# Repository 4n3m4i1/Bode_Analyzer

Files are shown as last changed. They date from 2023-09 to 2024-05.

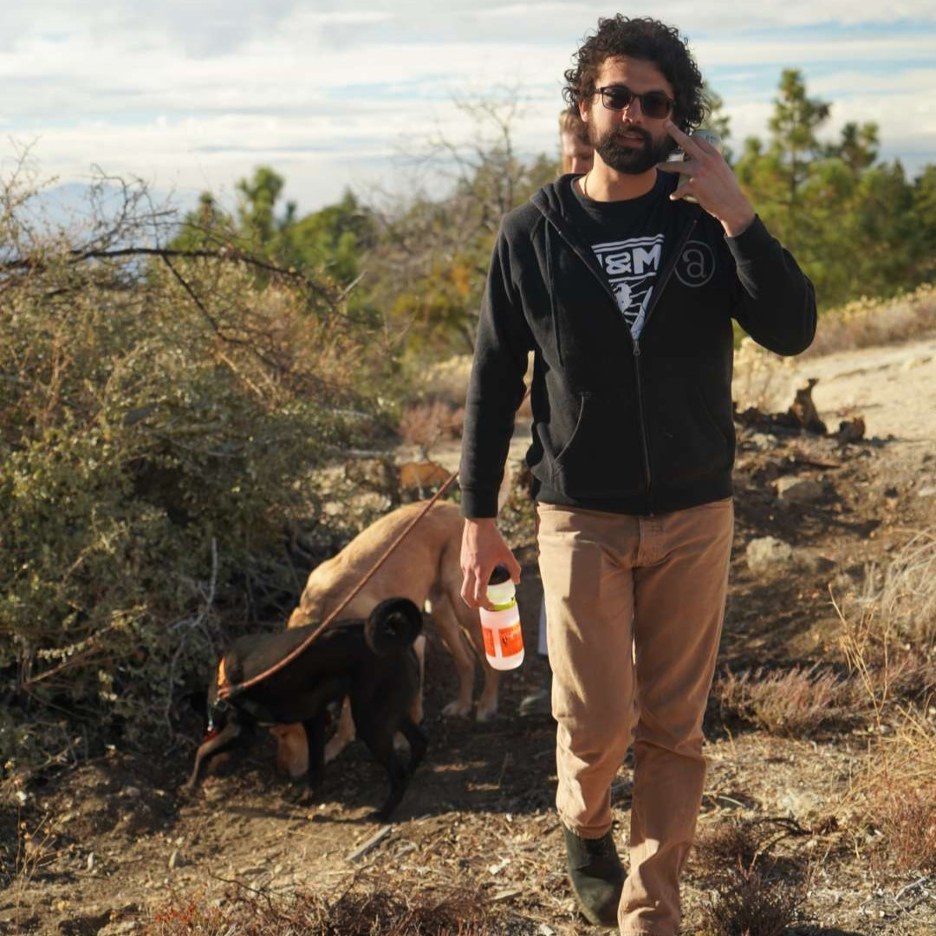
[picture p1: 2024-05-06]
App/FletApp/assets/JosephHobby.png

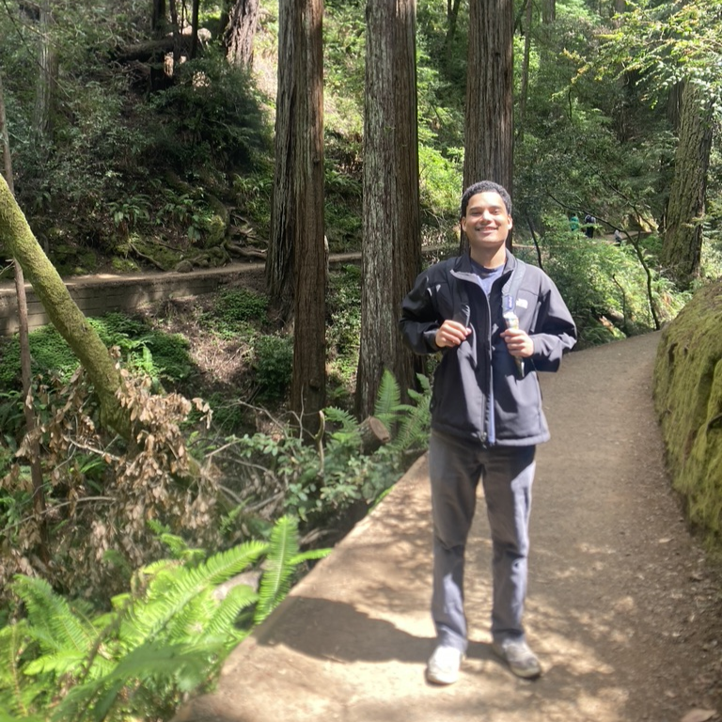
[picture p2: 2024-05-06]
App/FletApp/assets/ChristianHobby.png

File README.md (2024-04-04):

# Bode Bandits Analysis Tool
The Bode Bandits Analysis Tool provides frequency response characteristics of a multitude of filters.
A Python GUI allows interface with the tool, providing configuration and visual representations of the measured transfer function.  
  
## Hardware
Board and assembly files are provided in the repository, optimized for JLC's PCBA service.  
  
## Methods
The Least Mean Squared (LMS) adaptive filter methodology is implemented in a semi-real time fashion, allowing rapid characterization cycles to be made.  
All algorithms (LMS, FFT, Downsampling) are fully parametric, and largely user selectable on the fly. Automatic self-calibration corrects for  
component tolerance variations, VDDA magnitude, and the frontend anti-aliasing filter transfer function. DC calibration routines are run at  
startup, all transfer function calibration metrics are gathered at startup as well as upon change of any parametric setting.  
  

  
## Real Time Adjustment Parameters
- Range of frequency analysis (set ranges)
- Datapoint resolution (2^n)
- Acceptable LMS convergence error tolerances
  
## Required User Software 
- Python 3.9+
- That's it :)
  
## Repo Layout
- App: Contains the PC side of the project. Including the Python source and helper tools.
- HDL: Placeholder for potential HDL in the event a switch to a more PL based approach occurs.
- src: All C source for both the current main build as well as helper C files and feature tests.
- Documentation: All standard documentation as well as theory behind every working component, with test programs and scrips included.

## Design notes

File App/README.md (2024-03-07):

# Python GUI and Serial Input Functions

This implementation works for the data streaming test file Bode_Analyzer/src/tests/Datastreaming/Dynamic_data_output_testing

Please build this version and select the appropriate ports in the configuration 

Currently works with:
+ MacOS

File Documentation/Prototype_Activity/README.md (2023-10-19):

# Prototyping Activity
Every team member should create their own interpretation of an LMS adaptive filter.

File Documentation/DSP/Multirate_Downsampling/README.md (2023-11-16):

# Multirate Downsampling
Reduction of cost and space necessitates moving a multirate sampling solution into the digital domain.  
This example will show the process, pitfalls, and solutions with implementing such a mechanism.  
Specifically the simulation of a fixed high Fs ADC with a dynamic downsampler in the digital domain.  
In the context of this project this will allow variable rate FFT analysis and higher resolutions at lower  
frequency ranges without sacrificing analytical abilities at higher frequencies of interest.

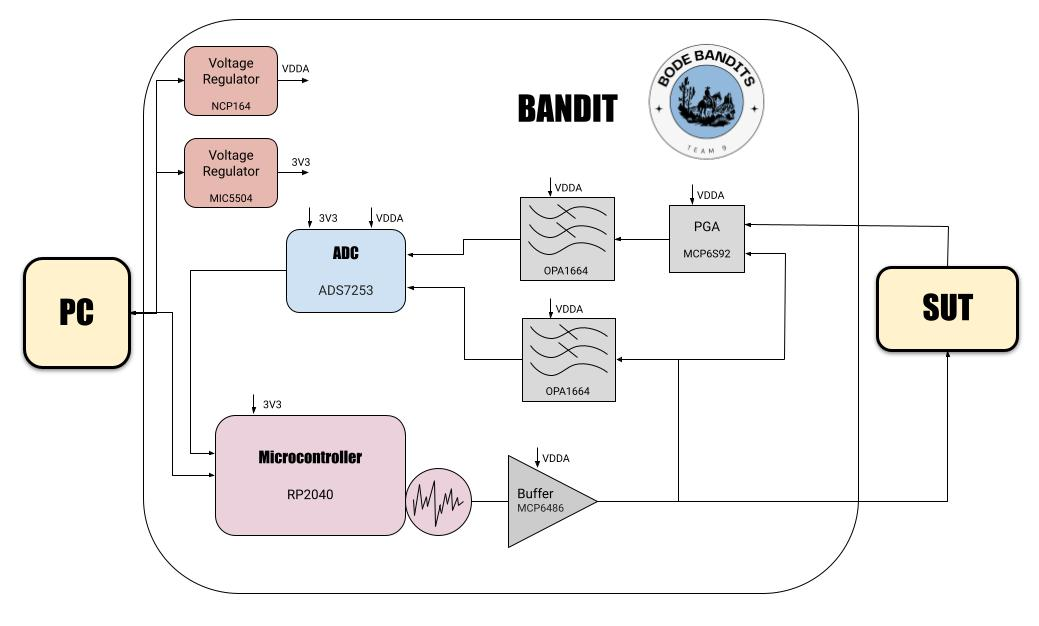
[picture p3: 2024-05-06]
App/FletApp/assets/HardwareDiagram.png

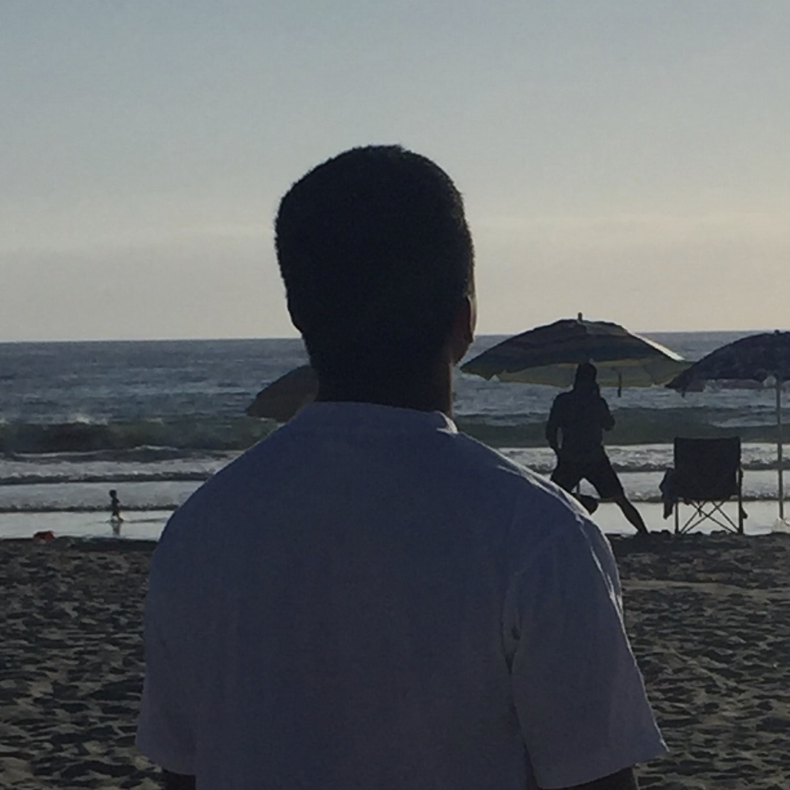
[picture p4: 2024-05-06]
App/FletApp/assets/LanceHobby.png

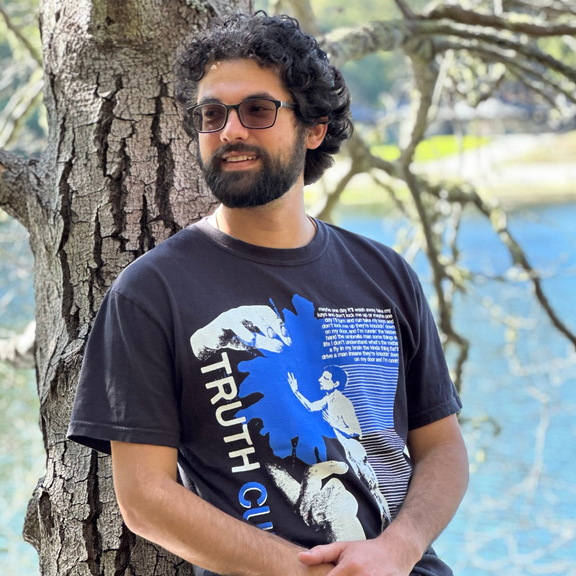
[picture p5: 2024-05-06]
App/FletApp/assets/Joseph.png

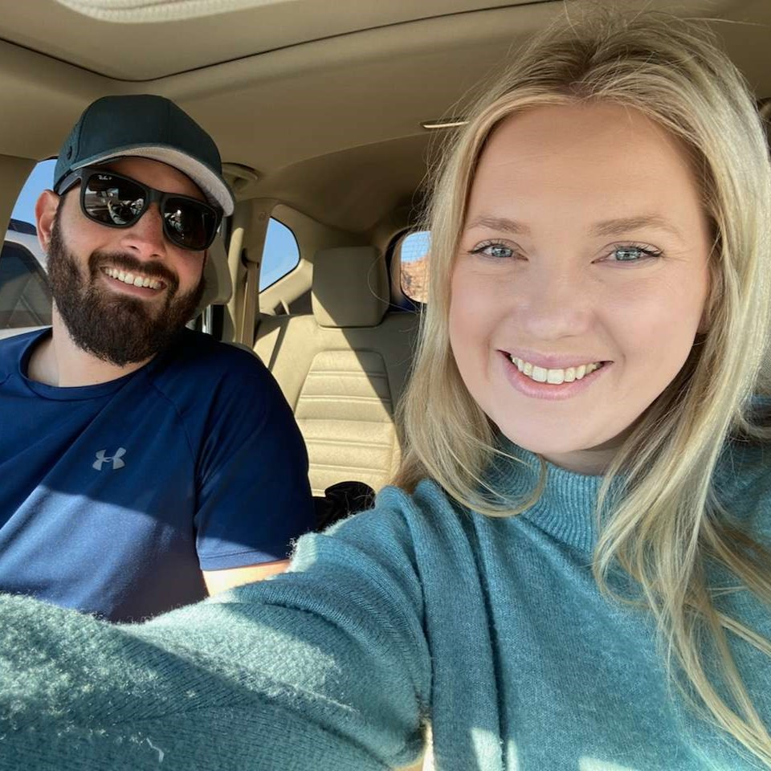
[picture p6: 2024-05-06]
App/FletApp/assets/JoshFam.png

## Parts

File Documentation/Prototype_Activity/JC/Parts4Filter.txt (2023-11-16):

200k Filter

Resistors:
2	10k
1	6k
1	5.5k
1	4k
1	2k
1	1.54k

Signal Capacitors:
5	100p 
1	75p
1	10p

Op Amps:
1	OPA1664

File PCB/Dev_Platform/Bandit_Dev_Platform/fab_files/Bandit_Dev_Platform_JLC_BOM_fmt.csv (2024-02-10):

Designator | Qty | Value | Footprint | LCSC Part Number
C1, C3, C6, C8, C12, C13, C15, C26, C28, C31, C33, C36, C48, C57, C61, C62, C64, C65, C67, C74 | 20 | 100n | Capacitor_SMD:C_0402_1005Metric | C307331
C2, C17, C18, C21, C22, C68 | 6 | 10u | Capacitor_SMD:C_0402_1005Metric | C15525
C4, C9, C14, C27, C29, C30 | 6 | 1u | Capacitor_SMD:C_0402_1005Metric | C52923
C5, C35, C49, C58 | 4 | 10n | Capacitor_SMD:C_0402_1005Metric | C15195
C7, C10, C19, C20, C41, C50 | 6 | 33p C0G | Capacitor_SMD:C_0402_1005Metric | C1562
C11, C34, C37, C63, C66 | 6 | 2u2 | Capacitor_SMD:C_0402_1005Metric | C12530
C16, C38, C46, C55 | 4 | 33p | C0G | Capacitor_SMD:C_0402_1005Metric | C1562
C23, C24 | 2 | 16n C0G | Capacitor_SMD:C_0402_1005Metric | C1549
C25, C69, C70, C71, C72, C73 | 5 | 10u 0805 | Capacitor_SMD:C_0805_2012Metric | C440198
C32 | 1 | 10n C0G | Capacitor_SMD:C_0402_1005Metric | C15195
C39, C40, C45, C47, C54, C56 | 6 | 100p | C0G | Capacitor_SMD:C_0402_1005Metric | C1546
C42, C51 | 2 | 15p C0G | Capacitor_SMD:C_0402_1005Metric | C1548
C43 | 1 | 220p | C0G | Capacitor_SMD:C_0402_1005Metric | C1530
C44, C53, C59, C60 | 4 | 47p | C0G | Capacitor_SMD:C_0402_1005Metric | C1567
C52 | 1 | 220p C0G | Capacitor_SMD:C_0402_1005Metric | C1530
D1 | 1 | LED | LED_SMD:LED_0805_2012Metric | C2297
D2 | 1 | LED_ABGR | LED_SMD:LED_Cree-PLCC4_2x2mm_CW | C2874119
FB1 | 1 | FerriteBead_Small | Inductor_SMD:L_0603_1608Metric | C1002
J5, J6 | 2 | BNC | BANDIT_PCB_Lib:DOSIN-801-0050 | C521210
P1 | 1 | USB_C_Plug_USB2.0 | Connector_USB:USB_C_Receptacle_GCT_USB4105-xx-A_16P_TopMnt_Horizontal | C963413
R1, R2, R3, R6 | 4 | 330R | Resistor_SMD:R_0402_1005Metric | C25104
R4, R5 | 2 | 27R | Resistor_SMD:R_0402_1005Metric | C25092
R7 | 1 | 100k | Resistor_SMD:R_0805_2012Metric | C149504
R8 | 1 | 150k | Resistor_SMD:R_0603_1608Metric | C22807
R9 | 1 | 50k | Resistor_SMD:R_0603_1608Metric | C23184
R10, R11 | 2 | 56k | Resistor_SMD:R_0603_1608Metric | C23206
R12, R14 | 2 | 1k | Resistor_SMD:R_0402_1005Metric | C11702
R13, R15, R25, R26 | 4 | 51k | Resistor_SMD:R_0402_1005Metric | C25794
R16, R17, R18, R19, R20, R42 | 6 | 10k | Resistor_SMD:R_0402_1005Metric | C25744
R21, R22, R23, R24 | 4 | 20R | Resistor_SMD:R_0402_1005Metric | C25092
R27 | 1 | 8.06 | Resistor_SMD:R_0402_1005Metric | C25077
R28, R32, R35, R39 | 4 | 15k | Resistor_SMD:R_0402_1005Metric | C25867
R29, R36 | 2 | 8k2 | Resistor_SMD:R_0603_1608Metric | C25981
R30, R37 | 2 | 15k | Resistor_SMD:R_0603_1608Metric | C22809
R31, R38 | 2 | 5k6 | Resistor_SMD:R_0603_1608Metric | C23189
R33, R40 | 2 | 6k2 | Resistor_SMD:R_0603_1608Metric | C4260
R34, R41 | 2 | 12k | Resistor_SMD:R_0402_1005Metric | C25752
U2 | 1 | RP2040 | Package_DFN_QFN:QFN-56-1EP_7x7mm_P0.4mm_EP3.2x3.2mm | C2040
U5 | 1 | W25Q16JVUXIQ_TR | ICDB_Curly:IC_W25Q16JVUXIQ_TR | C2843335
U11 | 1 | XC6206PxxxMR | Package_TO_SOT_SMD:SOT-23-3 | C5446
Y1 | 1 | 12.000 MHz, C9002 | Crystal:Crystal_SMD_3225-4Pin_3.2x2.5mm | C9002

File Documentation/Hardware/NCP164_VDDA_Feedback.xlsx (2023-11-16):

ADC Resolution | 12 | R Limit | 500000
Ideal Target VREF | 4.096
Part Number | Reference V | R1 | R2
NCP164ASNADJT1G | 1.1 | 50000
NCP164ASN180T1G | 1.8 | 50000
NCP164ASN280T1G | 2.8 | 50000
NCP164ASN330T1G | 3.3 | 50000

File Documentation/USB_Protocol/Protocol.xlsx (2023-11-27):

Packets
Name | Byte Number | Description
Standard Control Packet | 0x00-0x01 | Message ID
 | 0x02-0x40 | Message Specific
Message Types
Name | ID | Description | Byte Number
Ping | 0x0000 | Readback of all subsequent bytes in message to check connection | 0x02-0x40
Ping Response | 0x0001 | Readback of message data in Ping message | 0x02-0x40
RESERVED | 0x0002-0x000F
Set LMS Params | 0x0010 |  | 0x02-0x05 | Hardware Sampling Rate | uint32, Fixed 500k for BANDIT
 |  |  | 0x06-0x09 | Software Sampling Rate | uint32
 |  |  | 0x10 | Datatype | uint8
 |  |  | 0x11-0x12 | Target LMS Length | uint16
 |  |  | 0x13-0x14 | LMS Length Limit | uint16
 |  |  | 0x15-0x18 | Max Acceptable Error | Q15/Q31 Fixed point, set to 0 if unused
 |  |  | 0x19 | Start Now | uin8, if 1 start LMS process now
 |  |  | 0x20 | Loop | uint8, if 0 wait for Start Condition, if 0xFF loop forever, if 1-254 loop that many times
 |  |  | 0x21-0x40 | RESERVED

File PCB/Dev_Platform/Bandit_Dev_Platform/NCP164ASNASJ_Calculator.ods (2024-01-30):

VREF | VTGT | Scalar
1.1 | 4.096 | 2.72363636363636
PICK R1
R1 | 1.50E+05
R2 | 55073.4312416555
PICK R2
R1 | 136181.818181818
R2 | 5.00E+04

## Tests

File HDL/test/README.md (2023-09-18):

# Test and Development HDL
A collection of scratchpad Verilog that helps develop the main project.

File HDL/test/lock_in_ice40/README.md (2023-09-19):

# Lock in Test
A test of a fixed point lock in implementation for the iCE40-UP5k.  
Hardware target: Upduino3.1, iCE40-UP5k SG48

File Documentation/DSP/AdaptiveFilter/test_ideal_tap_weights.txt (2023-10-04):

0.000000000000000001
-0.000684893783392213
-0.002243092594496694
0.000000000000000001
0.017216487544020751
0.060604861756838498
0.126757470950199458
0.190091960088989709
0.216514412075680979
0.190091960088989709
0.126757470950199486
0.060604861756838546
0.017216487544020762
0.000000000000000001
-0.002243092594496697
-0.000684893783392215
0.000000000000000001

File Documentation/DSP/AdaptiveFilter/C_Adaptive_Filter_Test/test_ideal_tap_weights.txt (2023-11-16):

0.000000000000000000
-0.000011466433343440
-0.000048159680438716
-0.000070951498745996
0.000000000000000000
0.000226394896924650
0.000570593070542985
0.000843882357908127
0.000742644459879189
-0.000000000000000001
-0.001387330856962112
-0.002974017320060804
-0.003876072294410999
-0.003078546062261788
0.000000000000000002
0.004911281747189231
0.009897689392343489
0.012239432700612913
0.009302643950572093
-0.000000000000000005
-0.013947257358995015
-0.027649479941983943
-0.034045985830080311
-0.026173578588735643
0.000000000000000007
0.043288592274982135
0.096612134128292462
0.148460098539443669
0.186178664190551207
0.199977588313552862
0.186178664190551235
0.148460098539443669
0.096612134128292462
0.043288592274982128
0.000000000000000007
-0.026173578588735653
-0.034045985830080325
-0.027649479941983936
-0.013947257358995019
-0.000000000000000005
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

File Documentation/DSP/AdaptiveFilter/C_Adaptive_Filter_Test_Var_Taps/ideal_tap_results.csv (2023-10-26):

IDX | IDEAL_TAP
0 | 0.00000000000000
1 | -0.00001091022809
2 | 0.00003691750457
3 | 0.00004444100803
4 | -0.00022922248370
5 | 0.00014180415650
6 | 0.00043739642997
7 | -0.00080294793796
8 | -0.00007934189430
9 | 0.00166191275359
10 | -0.00150465174576
11 | -0.00150663631703
12 | 0.00404383713989
13 | -0.00130266073992
14 | -0.00538037299278
15 | 0.00705559340679
16 | 0.00195029364228
17 | -0.01264269610401
18 | 0.00848122079784
19 | 0.01139998150633
20 | -0.02298546385206
21 | 0.00364412373121
22 | 0.03137342546969
23 | -0.03431395331964
24 | -0.01742791236150
25 | 0.07350945086669
26 | -0.04325697180722
27 | -0.10686930523952
28 | 0.29453439078266
29 | 0.61999651565494
30 | 0.29453439078266
31 | -0.10686930523952
32 | -0.04325697180722
33 | 0.07350945086669
34 | -0.01742791236150
35 | -0.03431395331964
36 | 0.03137342546969
37 | 0.00364412373121
38 | -0.02298546385206
39 | 0.01139998150633
40 | 0.00848122079784
41 | -0.01264269610401
42 | 0.00195029364228
43 | 0.00705559340679
44 | -0.00538037299278
45 | -0.00130266073992
46 | 0.00404383713989
47 | -0.00150663631703
48 | -0.00150465174576
49 | 0.00166191275359
50 | -0.00007934189430
51 | -0.00080294793796
52 | 0.00043739642997
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

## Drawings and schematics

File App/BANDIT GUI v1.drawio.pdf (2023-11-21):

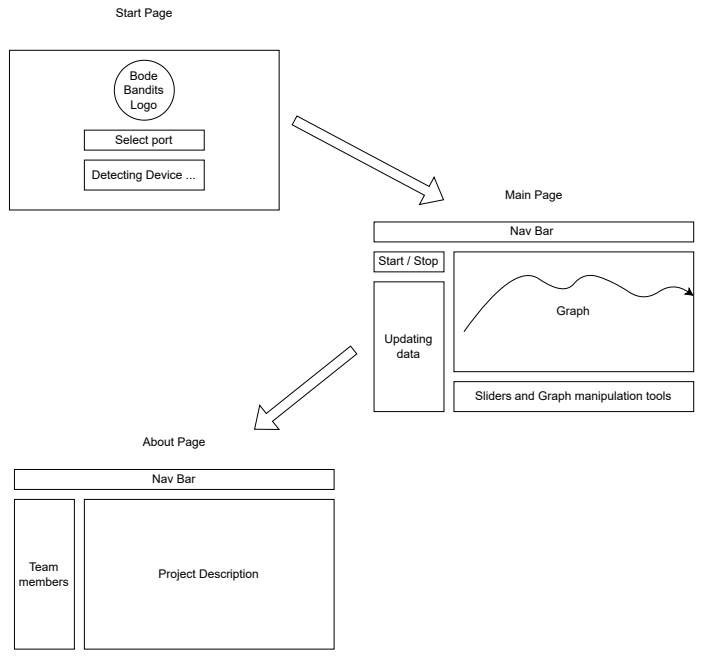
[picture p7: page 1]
Graph; Updating data; Nav Bar; Start / Stop; Main Page; Start Page; Select port; Detecting Device ...; Bode Bandits Logo; About Page; Team; members; Project Description

Sliders and Graph manipulation tools

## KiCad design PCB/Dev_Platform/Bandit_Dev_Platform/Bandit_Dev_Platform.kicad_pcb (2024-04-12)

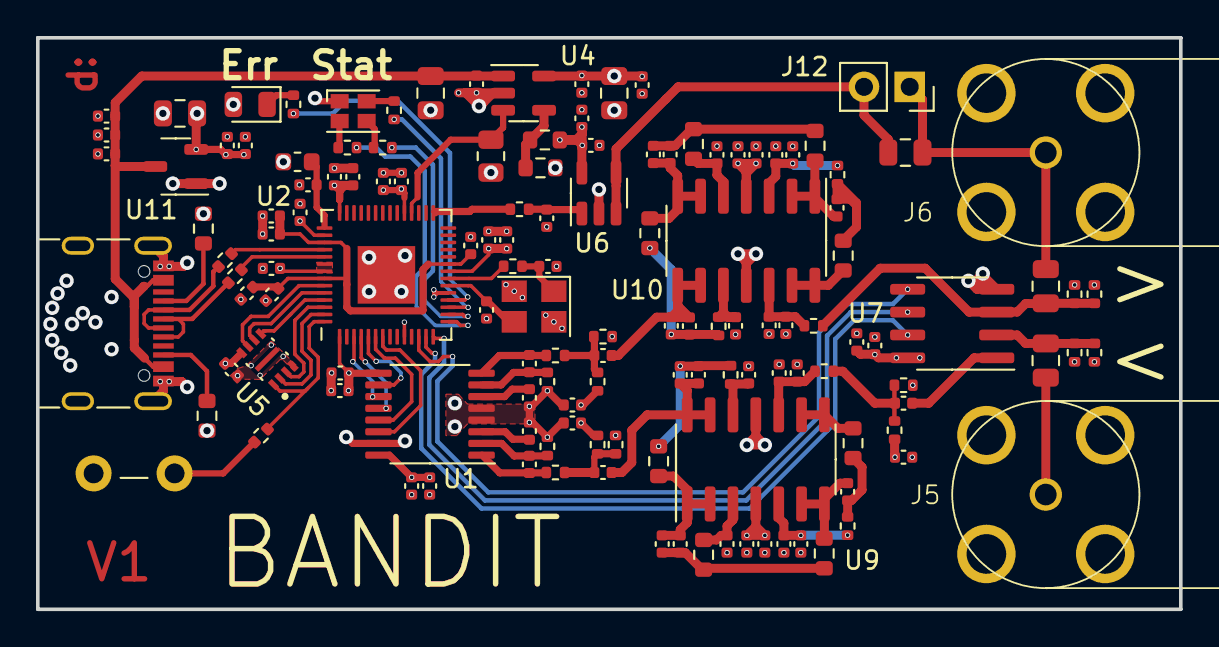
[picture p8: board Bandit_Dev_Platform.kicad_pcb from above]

Board: 4 copper layers, 63.5 x 31.8 mm, 136 parts (0 on the bottom side), 79 nets.

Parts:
C1, C3, C3#2, C6, C8, C12, C13, C15, C26, C28, C31, C33, C36, C48, C57, C61, C62, C64, C65, C67, C74: 100n; C_0402_1005Metric
C2, C17, C18, C21, C22, C68: 10u; C_0402_1005Metric
C4, C9, C14, C27, C29, C30: 1u; C_0402_1005Metric
C5, C35, C49, C58: 10n; C_0402_1005Metric
C7, C10, C16, C19, C20, C38, C41, C46, C50, C55: 33p C0G; C_0402_1005Metric
C11, C34, C37, C63, C66, C70: 2u2; C_0402_1005Metric
C23, C24: 16n C0G; C_0402_1005Metric
C25, C69, C71, C72, C73, C75: 10u 0805; C_0805_2012Metric
C32: 10n C0G; C_0402_1005Metric
C39, C40, C45, C47, C54, C56: 100p C0G; C_0402_1005Metric
C42, C51: 15p C0G; C_0402_1005Metric
C43, C52: 220p C0G; C_0402_1005Metric
C44, C53, C59, C60: 47p C0G; C_0402_1005Metric
D1: LED; LED_0805_2012Metric
D2: LED_ABGR; LED_Cree-PLCC4_2x2mm_CW
FB1: FerriteBead_Small; L_0603_1608Metric
J5, J6: BNC; DOSIN-801-0050
J12: Conn_01x02_Pin; PinSocket_1x02_P2.54mm_Vertical
P1: USB_C_Plug_USB2.0; USB_C_Receptacle_GCT_USB4105-xx-A_16P_TopMnt_Horizontal
R1, R2, R3, R6: 330R; R_0402_1005Metric
R4, R5: 27R; R_0402_1005Metric
R7: 10k; R_0805_2012Metric
R8: 150k; R_0603_1608Metric
R9: 50k; R_0603_1608Metric
R10, R11: 56k; R_0603_1608Metric
R12, R14: 1k; R_0402_1005Metric
R13, R15, R25, R26: 51k; R_0402_1005Metric
R16, R17, R18, R19, R20, R42: 10k; R_0402_1005Metric
R21, R22, R23, R24: 20R; R_0402_1005Metric
R27: 8.06; R_0402_1005Metric
R28, R32, R35, R39: 15k; R_0402_1005Metric
R29, R36: 8k2; R_0603_1608Metric
R30, R37: 15k; R_0603_1608Metric
R31, R38: 5k6; R_0603_1608Metric
R33, R40: 6k2; R_0603_1608Metric
R34, R41: 12k; R_0402_1005Metric
SW1: SW_SPST; SW_PUSH_6mm
U1: AD7253; TSSOP-16_4.4x5mm_P0.65mm
U2: RP2040; QFN-56-1EP_7x7mm_P0.4mm_EP3.2x3.2mm
U4: NCP164ASNADJT1G; SOT-23-5
U5: W25Q16JVUXIQ_TR; IC_W25Q16JVUXIQ_TR
U6: MCP6486UT-E/OT; SOT-23-5
U7: MCP6S92-E/SN; SOIC-8_3.9x4.9mm_P1.27mm
U9, U10: OPA1664; SOIC-14_3.9x8.7mm_P1.27mm
U11: XC6206PxxxMR; SOT-23-3
Y1: 12.000 MHz, C9002; Crystal_SMD_3225-4Pin_3.2x2.5mm

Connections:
+1V1: C33.1, C34.1, C62.1, C63.1, C64.1, U2.23 (DVDD), U2.45 (VREG_VOUT), U2.50 (DVDD)
+3V3: C1.1, C28.1, C29.1, C35.1, C36.1, C37.1, C61.1, C65.1, C66.1, C67.1, C68.1, C69.1, C70.1, C74.1, D1.2 (A), D2.1 (A), FB1.2, U1.9 (DVDD), U2.1 (IOVDD), U2.10 (IOVDD), U2.22 (IOVDD), U2.33 (IOVDD), U2.42 (IOVDD), U2.44 (VREG_IN), U2.48 (USB_VDD), U2.49 (IOVDD), U5.8 (VCC), U11.2 (VO)
/ADC_CSN: U1.11 (~CS), U2.3 (GPIO1)
/ADC_SCK: U1.12 (SCLK), U2.4 (GPIO2)
/ADC_SDI: U1.10 (SDI), U2.5 (GPIO3)
/ADC_SDO_A: U1.13 (SDO_A), U2.6 (GPIO4)
/ADC_SDO_B: U1.14 (SDO_B), U2.7 (GPIO5)
/CLK_12M: C10.1, U2.20 (XIN), Y1.3
/FLASH_IO0: U2.53 (QSPI_SD0), U5.5 (DI(IO0))
/FLASH_IO1: U2.55 (QSPI_SD1), U5.2 (DO(IO1))
/FLASH_IO2: U2.54 (QSPI_SD2), U5.3 (IO2)
/FLASH_IO3: U2.51 (QSPI_SD3), U5.7 (IO3)
/FLASH_SCK: U2.52 (QSPI_SCLK), U5.6 (CLK)
/LED_B: R1.2, U2.17 (GPIO14)
/LED_G: R2.2, U2.16 (GPIO13)
/LED_R: R3.2, U2.15 (GPIO12)
/PDM_WGN: R27.2, U2.29 (GPIO18)
/PGA_SCK: U2.13 (GPIO10), U7.7 (SCK)
/PGA_SI: U2.14 (GPIO11), U7.6 (SI)
/SE_SIG_A: C18.2, C39.1, C52.1, U10.8, U10.9 (-)
/SE_SIG_B: C17.2, C40.1, C43.1, U9.13 (-), U9.14
/SIG_IN: C2.1, R16.2, R17.1, R34.1
/USB_CC: P1.A5 (CC), R10.1
/USB_D+: R5.2, U2.47 (USB_DP)
/USB_D-: R4.2, U2.46 (USB_DM)
/USB_VCONN: P1.B5 (VCONN), R11.1
/USER_LED: R6.2, U2.18 (GPIO15)
/VDDA_EN: R7.2, U2.32 (GPIO21), U4.3 (EN)
/WGN_OUT: C73.2, J12.2, U6.3 (VIN-), U6.4 (VOUT)
/WGN_OUT_PORT: C72.1, C73.1, J6.1 (In), J12.1
/WGN_PGA_IN: C72.2, R13.2, R15.1, R41.1, U7.3 (CH1)
/XOUT: C7.2, R14.2, Y1.1
/~FLASH_CSN: R12.1, U2.56 (QSPI_SS), U5.1 (~CS)
/~PGA_CS: U2.12 (GPIO9), U7.5 (~CS)
GND: C1.2, C3.2, C3#2.2, C4.2, C5.2, C6.2, C7.1, C8.2, C9.2, C10.2, C11.2, C12.2, C13.2, C14.2, C15.2, C16.1, C19.1, C20.1, C21.2, C22.2, C26.2, C27.2, C28.2, C29.2, C30.2, C31.2, C32.2, C33.2, C34.2, C35.2, C36.2, C37.2, C38.1, C41.1, C42.1, C44.1, C46.1, C48.2, C49.2, C50.1, C51.1, C53.1, C55.1, C57.2, C58.2, C61.2, C62.2, C63.2, C64.2, C65.2, C66.2, C67.2, C68.2, C69.2, C70.2, C71.2, C74.2, C75.2, J5.2 (Ext), J6.2 (Ext), P1.A1 (GND), P1.A12 (GND), P1.B1 (GND), P1.B12 (GND), P1.S1 (SHIELD), R7.1, R9.1, R10.2, R11.2, R15.2, R17.2, R19.2, R21.1, R24.1, R26.2, R42.2, SW1.2 (B), U1.4 (REFGND_A), U1.5 (REFGND_B), U1.15 (GND), U2.19 (TESTEN), U2.57 (GND), U4.2 (GND), U5.4 (GND), U6.2 (VSS), U7.4 (VSS), U9.11 (V-), U10.11 (V-), U11.1 (GND), Y1.2, Y1.4
unnamed: C17.1, R18.2, R19.1, R23.1
unnamed: C18.1, R20.2, R22.1, R42.1
unnamed: C39.2, C52.2, R35.1, R36.2
unnamed: C40.2, C43.2, R28.1, R29.2
unnamed: C45.2, C60.2, R30.1, R31.2
unnamed: C47.2, R32.1, R33.2
unnamed: C54.2, C59.2, R37.1, R38.2
unnamed: C56.2, R39.1, R40.2
unnamed: D1.1 (K), R6.1
unnamed: D2.2 (BK), R1.1
unnamed: D2.3 (GK), R2.1
unnamed: D2.4 (RK), R3.1
unnamed: C25.1, J5.1 (In)
unnamed: P1.A6 (D+), R5.1
unnamed: P1.A7 (D-), R4.1
unnamed: R12.2, SW1.1 (A)
unnamed: C24.2, R24.2, U1.2 (AINM_A)
unnamed: C23.2, R21.2, U1.7 (AINM_B)
unnamed: C24.1, R23.2, U1.1 (AINP_A)
unnamed: C23.1, R22.2, U1.8 (AINP_B)
unnamed: C22.1, U1.3 (REFIO_A)
unnamed: C21.1, U1.6 (REFIO_B)
unnamed: C11.1, FB1.1, U2.43 (ADC_AVDD)
unnamed: R14.1, U2.21 (XOUT)
unnamed: R8.1, R9.2, U4.4 (PG/ADJ)
unnamed: C32.1, R27.1, U6.1 (VIN+)
unnamed: C25.2, R25.2, R26.1, U7.2 (CH0)
unnamed: C2.2, U7.1 (VOUT)
unnamed: C44.2, R30.2, U9.3 (+)
unnamed: C45.1, C60.1, R29.1, U9.1, U9.2 (-)
unnamed: C16.2, C46.2, R32.2, U9.5 (+)
unnamed: C47.1, R31.1, U9.6 (-), U9.7
unnamed: C19.2, C50.2, R34.2, U9.10 (+)
unnamed: R33.1, U9.8, U9.9 (-)
unnamed: C42.2, R28.2, U9.12 (+)
unnamed: C38.2, C55.2, R39.2, U10.3 (+)
unnamed: C56.1, R38.1, U10.1, U10.2 (-)
unnamed: C53.2, R37.2, U10.5 (+)
unnamed: C54.1, C59.1, R36.1, U10.6 (-), U10.7
unnamed: C51.2, R35.2, U10.10 (+)
unnamed: C20.2, C41.2, R41.2, U10.12 (+)
unnamed: R40.1, U10.13 (-), U10.14
VBUS: C3.1, C4.1, C5.1, C6.1, C75.1, P1.A4 (VBUS), P1.A9 (VBUS), P1.B4 (VBUS), P1.B9 (VBUS), U4.1 (VIN), U11.3 (VI)
VDDA: C3#2.1, C8.1, C9.1, C12.1, C13.1, C14.1, C15.1, C26.1, C27.1, C30.1, C31.1, C48.1, C49.1, C57.1, C58.1, C71.1, R8.2, R13.1, R16.1, R18.1, R20.1, R25.1, U1.16 (AVDD), U4.5 (VOUT), U6.5 (VDD), U7.8 (VDD), U9.4 (V+), U10.4 (V+)

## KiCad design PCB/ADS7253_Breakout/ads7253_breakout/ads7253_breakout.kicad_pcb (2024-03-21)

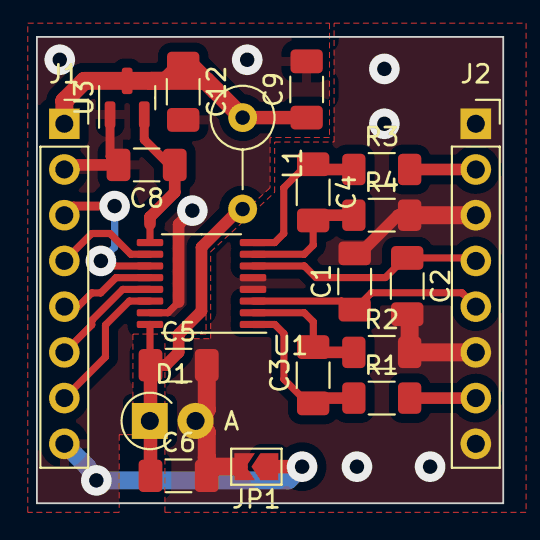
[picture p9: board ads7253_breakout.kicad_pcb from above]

Board: 2 copper layers, 25.9 x 25.9 mm, 20 parts (0 on the bottom side), 18 nets.

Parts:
C1, C2: 10u; C_1206_3216Metric_Pad1.33x1.80mm_HandSolder
C3, C4: 16p; C_1206_3216Metric_Pad1.33x1.80mm_HandSolder
C5, C9, C12: 1u; C_1206_3216Metric_Pad1.33x1.80mm_HandSolder
C6, C8: 100n; C_1206_3216Metric_Pad1.33x1.80mm_HandSolder
D1: D_Zener; D_T-1_P2.54mm_Vertical_AnodeUp
J1, J2: Conn_01x08_Pin; PinSocket_1x08_P2.54mm_Vertical
JP1: Jumper_2_Bridged; SolderJumper-2_P1.3mm_Open_TrianglePad1.0x1.5mm
L1: L; L_Axial_L7.0mm_D3.3mm_P5.08mm_Vertical_Fastron_MICC
R1, R2, R3, R4: 20R; R_1206_3216Metric_Pad1.30x1.75mm_HandSolder
U1: AD7253; TSSOP-16_4.4x5mm_P0.65mm
U3: MCP1700x-330xxTT; SOT-23

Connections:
+3V3: C8.1, U1.9 (DVDD), U3.2 (VO)
+5C: C9.1, C12.1, J1.1, L1.1, U3.3 (VI)
/AINP_A_1: J2.7, R1.2
/AINP_B_8: J2.2, R3.2
/REFDAC_A: C1.1, J2.5, U1.3 (REFIO_A)
/REFDAC_B: C2.1, J2.4, U1.6 (REFIO_B)
/SPI_CSN: J1.3, U1.11 (~CS)
/SPI_SCLK: J1.5, U1.12 (SCLK)
/SPI_SDI: J1.4, U1.10 (SDI)
/SPI_SDOA: J1.6, U1.13 (SDO_A)
/SPI_SDOB: J1.7, U1.14 (SDO_B)
GND: C8.2, C9.2, C12.2, J1.2, J1.8, JP1.1 (A), U1.15 (GND), U3.1 (GND)
GNDA: C1.2, C2.2, C5.2, C6.2, D1.2 (A), J2.1, J2.3, J2.6, J2.8, JP1.2 (B), R2.2, R4.2, U1.4 (REFGND_A), U1.5 (REFGND_B)
unnamed: C3.2, R2.1, U1.2 (AINM_A)
unnamed: C4.2, R4.1, U1.7 (AINM_B)
unnamed: C3.1, R1.1, U1.1 (AINP_A)
unnamed: C4.1, R3.1, U1.8 (AINP_B)
VDDA: C5.1, C6.1, D1.1 (K), L1.2, U1.16 (AVDD)

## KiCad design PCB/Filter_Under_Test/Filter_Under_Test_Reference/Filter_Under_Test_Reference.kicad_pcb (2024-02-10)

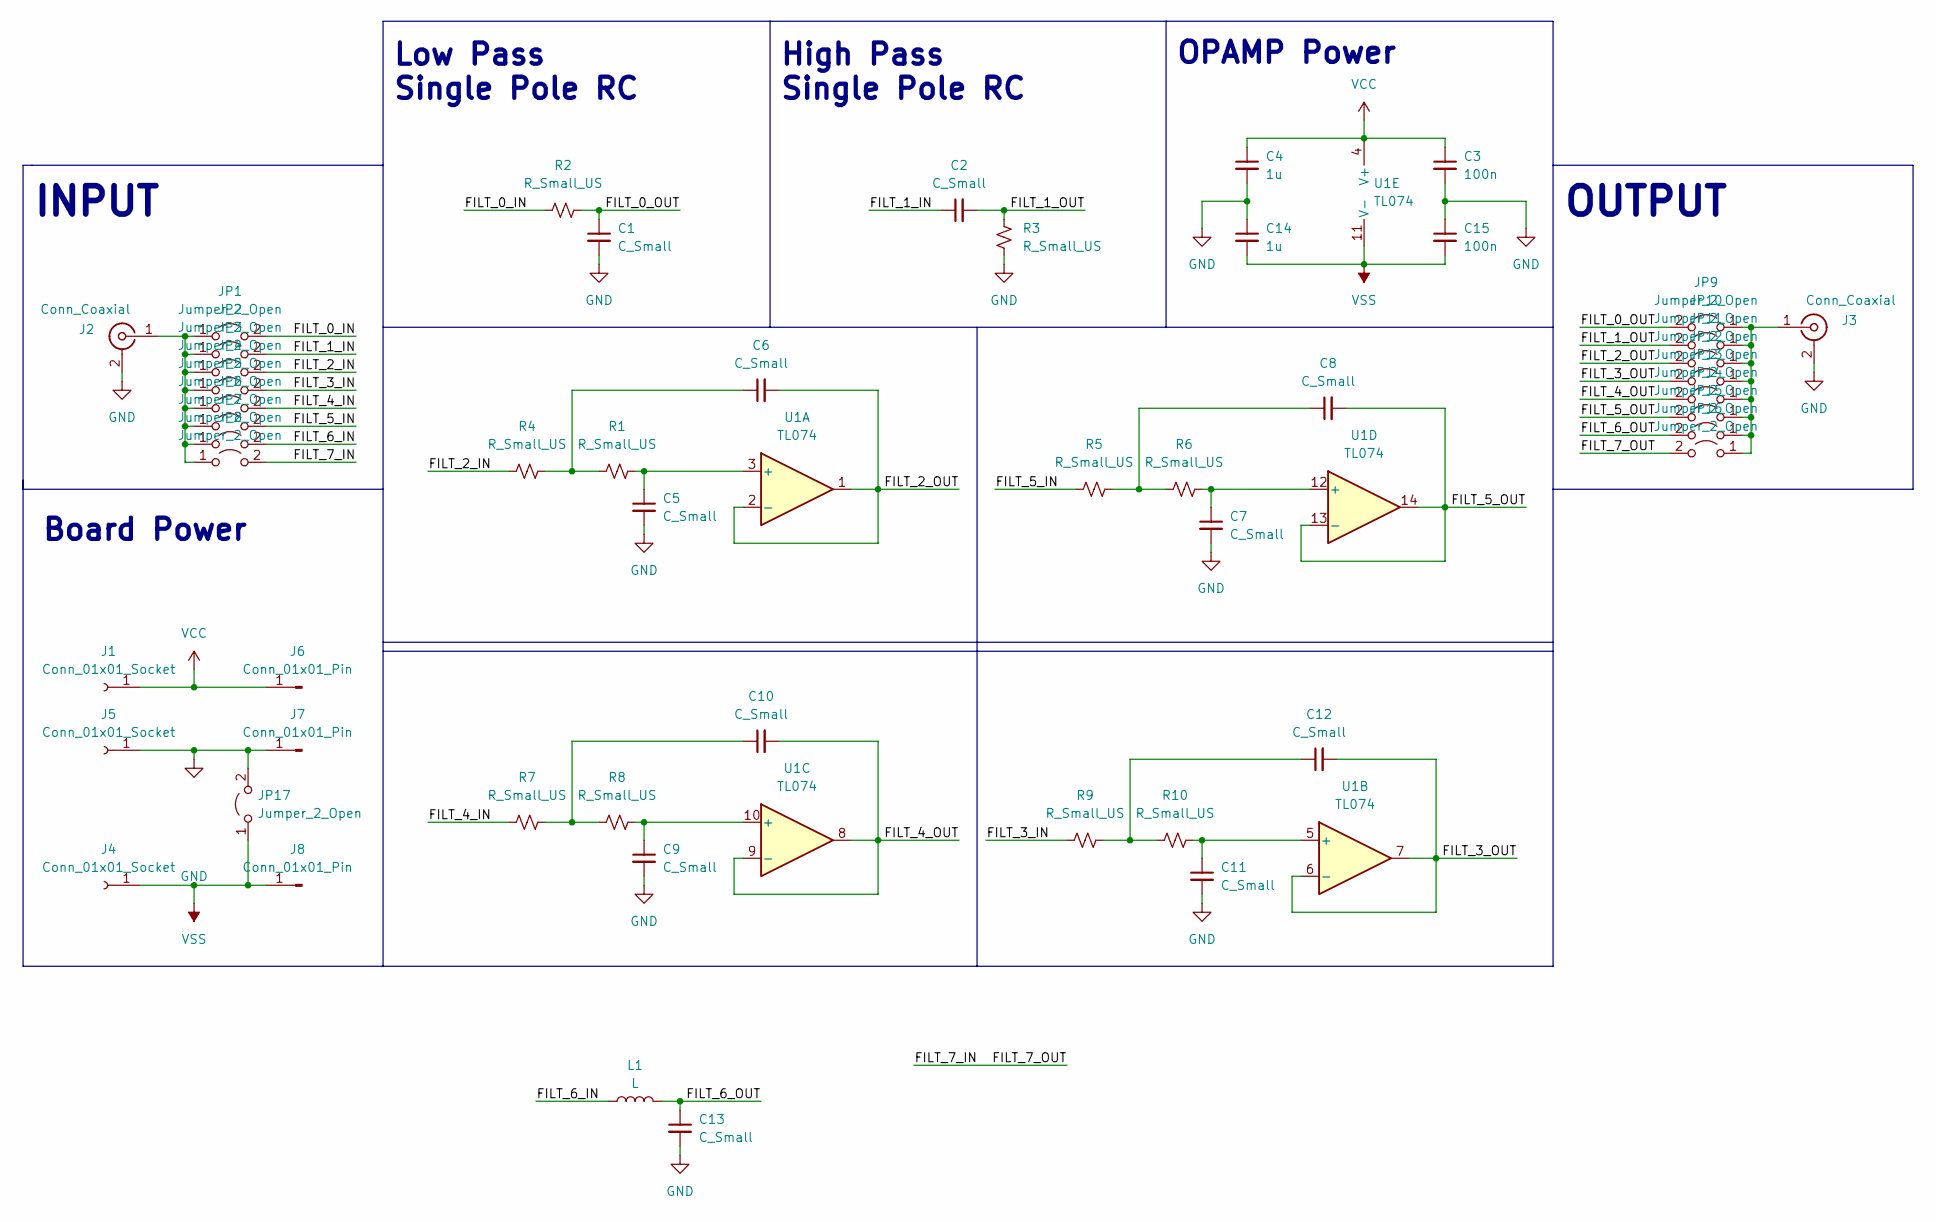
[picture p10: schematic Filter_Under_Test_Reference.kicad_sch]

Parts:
C1, C2, C5, C6, C7, C8, C9, C10, C11, C12, C13: C_Small; C_1206_3216Metric_Pad1.33x1.80mm_HandSolder
C3, C15: 100n; C_0805_2012Metric_Pad1.18x1.45mm_HandSolder
C4, C14: 1u; C_0805_2012Metric_Pad1.18x1.45mm_HandSolder
J1, J4, J5: Conn_01x01_Socket; Keystone 575 Banana
J2, J3: Conn_Coaxial; BNC_THT
J6, J7, J8: Conn_01x01_Pin; PinSocket_1x01_P2.54mm_Vertical
JP1, JP2, JP3, JP4, JP5, JP6, JP7, JP8, JP9, JP10, JP11, JP12, JP13, JP14, JP15, JP16, JP17: Jumper_2_Open; PinSocket_1x02_P2.54mm_Vertical
L1: L; L_Axial_L5.3mm_D2.2mm_P7.62mm_Horizontal_Vishay_IM-1
R1, R2, R3, R4, R5, R6, R7, R8, R9, R10: R_Small_US; R_1206_3216Metric_Pad1.30x1.75mm_HandSolder
U1: TL074; SOT23 Thin 14

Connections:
/FILT_0_IN: JP1.2 (B), R2.1
/FILT_0_OUT: C1.1, JP9.2 (B), R2.2
/FILT_1_IN: C2.1, JP2.2 (B)
/FILT_1_OUT: C2.2, JP10.2 (B), R3.1
/FILT_2_IN: JP3.2 (B), R4.1
/FILT_2_OUT: C6.2, JP11.2 (B), U1.1, U1.2 (-)
/FILT_3_IN: JP4.2 (B), R9.1
/FILT_3_OUT: C12.2, JP12.2 (B), U1.6 (-), U1.7
/FILT_4_IN: JP5.2 (B), R7.1
/FILT_4_OUT: C10.2, JP13.2 (B), U1.8, U1.9 (-)
/FILT_5_IN: JP6.2 (B), R5.1
/FILT_5_OUT: C8.2, JP14.2 (B), U1.13 (-), U1.14
/FILT_6_IN: JP7.2 (B), L1.1
/FILT_6_OUT: C13.1, JP15.2 (B), L1.2
/FILT_7_IN: JP8.2 (B), JP16.2 (B)
GND: C1.2, C3.2, C4.2, C5.2, C7.2, C9.2, C11.2, C13.2, C14.1, C15.1, J2.2 (Ext), J3.2 (Ext), J5.1, J7.1, JP17.2 (B), R3.2
unnamed: C6.1, R1.1, R4.2
unnamed: C8.1, R5.2, R6.1
unnamed: C10.1, R7.2, R8.1
unnamed: C12.1, R9.2, R10.1
unnamed: J2.1 (In), JP1.1 (A), JP2.1 (A), JP3.1 (A), JP4.1 (A), JP5.1 (A), JP6.1 (A), JP7.1 (A), JP8.1 (A)
unnamed: J3.1 (In), JP9.1 (A), JP10.1 (A), JP11.1 (A), JP12.1 (A), JP13.1 (A), JP14.1 (A), JP15.1 (A), JP16.1 (A)
unnamed: C5.1, R1.2, U1.3 (+)
unnamed: C11.1, R10.2, U1.5 (+)
unnamed: C9.1, R8.2, U1.10 (+)
unnamed: C7.1, R6.2, U1.12 (+)
VCC: C3.1, C4.1, J1.1, J6.1, U1.4 (V+)
VSS: C14.2, C15.2, J4.1, J8.1, JP17.1 (A), U1.11 (V-)

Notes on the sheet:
High Pass Single Pole RC
Low Pass Single Pole RC
OPAMP Power
OUTPUT
Board Power
INPUT

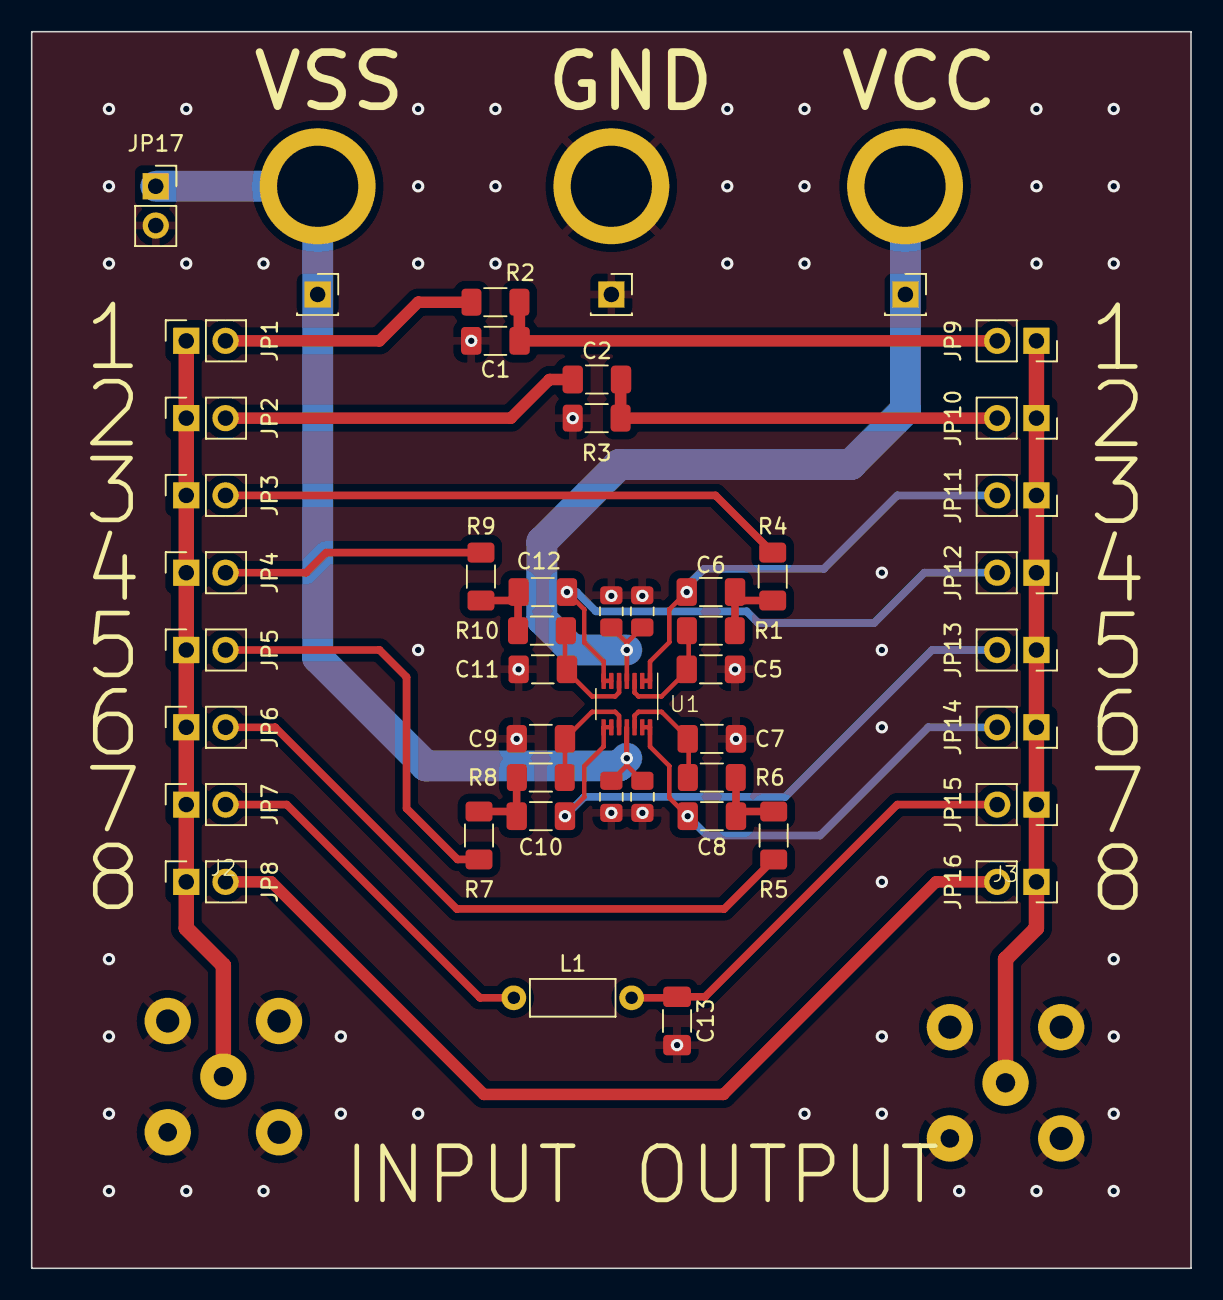
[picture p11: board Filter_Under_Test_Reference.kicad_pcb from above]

Board: 2 copper layers, 75.0 x 80.0 mm, 52 parts (0 on the bottom side), 28 nets.

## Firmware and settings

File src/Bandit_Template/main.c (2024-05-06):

/*
    Testing Defines
    DO NOT UNCOMMENT UNLESS YOU KNOW EXACTLY WHAT YOU'RE DOING!!!!!!
*/
//#define FORCE_SAMPLING_4_TESTING
#define NO_DEBUG_LED
//#define FORCESEND_TESTING
//#define FORCESEND_FAKETAPS
//#define FORCESEND_NOFFT
//#define FORCESEND_USE_REALDATA
//#define SEND_RAW_2_OUTPUT

#ifdef FORCESEND_USE_REALDATA
#include "realdata.h"
// For debug only
#include "dummy_taps.h"
#endif


#include <stdio.h>
#include "pico/stdlib.h"
#include "pico/multicore.h"
#include "hardware/i2c.h"
#include "hardware/spi.h"
#include "hardware/timer.h"
#include "hardware/pwm.h"
#include "hardware/dma.h"

#include "tusb.h"
#include "tusb_config.h"

#include "Bode_Bandit.h"


  //////////////////////////////////////////////////////////////////////
 //////////////////   GLOBAL PREALLOC BUFFERS   ///////////////////////
//////////////////////////////////////////////////////////////////////
// Preserve the abilitiy to transfer to additional buffers
//  in currently General allocated memory to interleave processing/sampling
//  more!

/*
    Current Memory Access Scheme:
    Time:       0           1           2           3
    Core 0:     Settings    N/A         N/A         FR FI
    Core 1:     XN DN       XN DN       Shared      XN DN
    Reason:     Sampling    LMS         FFT Copy    FFT / Sampling

    In theory zero contention, minor waits incurred.
    Adding a tertiary exclusive access bank would allow
    Core 0 processing during time slots 1 and 2, probably working
    on parallelized downsampling or precalculating errors for h_hat
    updates for LMS. (That's like... a good idea)
*/


  //////////////////////////////////////////////////////////////////////
 /////////////////////    GLOBAL ALLOCATIONS    ///////////////////////
//////////////////////////////////////////////////////////////////////
// Core 1 -> 0 transfer buffers
struct Transfer_Data {
    volatile bool       updated;
    volatile bool       calibration_data;
    volatile uint16_t   len;
    volatile Q15        data[TOTAL_ADAPTIVE_FIR_LEN];

    volatile uint32_t   lms_samples_processed;
    volatile Q15        lms_error;
    volatile uint16_t   lms_error_attempts;
};

struct Transfer_Data ICTXFR_A;


struct BANDIT_SETTINGS  Global_Bandit_Settings;



  //////////////////////////////////////////////////////////////////////
 /////////////////////    CORE 0 ALLOCATIONS    ///////////////////////
//////////////////////////////////////////////////////////////////////
// FFT Tap Buffers
CORE_0_MEM Q15 FR_BUFF[TOTAL_ADAPTIVE_FIR_LEN];
CORE_0_MEM Q15 FI_BUFF[TOTAL_ADAPTIVE_FIR_LEN];

// FFT Averaging buffer
CORE_0_MEM Q15 FFT_AVG_BUFF[TOTAL_ADAPTIVE_FIR_LEN];
CORE_0_MEM Q15 FFT_CAL_BUFF[TOTAL_ADAPTIVE_FIR_LEN];

// Reserve Buffer for Stored Results
CORE_0_MEM Q15 RESULTS_BUFFER[TOTAL_ADAPTIVE_FIR_LEN];


volatile CORE_0_MEM uint16_t USB_STATE;
volatile CORE_0_MEM uint16_t USB_NEXT_STATE;

volatile CORE_0_MEM bool SKIP_FFT = false;

CORE_0_MEM uint8_t  BS_RX_BF[BS_BF_LEN];
volatile CORE_0_MEM bool CORE_0_SKIP_FFT = false;
  //////////////////////////////////////////////////////////////////////
 /////////////////////    CORE 1 ALLOCATIONS    ///////////////////////
//////////////////////////////////////////////////////////////////////
struct BANDIT_LED_COLORS {
    uint8_t R;
    uint8_t G;
    uint8_t B;
    uint8_t U;
};

struct CORE_1_MEM BANDIT_LED_COLORS Bandit_RGBU;

// Sampling Banks
CORE_1_MEM Q15 X_N_0[TOTAL_BUFF_LEN];
CORE_1_MEM Q15 D_N_0[TOTAL_BUFF_LEN];

// LMS FIR For Producing Y[n]
CORE_1_MEM Q15 LMS_FIR_BANK[TOTAL_ADAPTIVE_FIR_LEN + DEFAULT_LMS_TAP_LEN];
CORE_1_MEM Q15 LMS_H_HATS[TOTAL_ADAPTIVE_FIR_LEN + DEFAULT_LMS_TAP_LEN];

CORE_1_MEM Q15 LMS_H_HATS_AVG[TOTAL_ADAPTIVE_FIR_LEN + DEFAULT_LMS_TAP_LEN];

CORE_1_MEM Q15 LMS_H_HATS_CORRECTION[TOTAL_ADAPTIVE_FIR_LEN + DEFAULT_LMS_TAP_LEN];

struct CORE_1_MEM BANDIT_CORE_1_DEBUG_REPORT Bandit_Debug_Report;

// Core 1 Defines
#define ADCRES_BITS     12u
#define ADC_RES_CODES   (1u << ADCRES_BITS)
#define ADC_VREF_CODE   0x108                   // ~2.19 V from ADS7253 DAC

#define ADC_PIO         pio1
CORE_1_MEM uint16_t     tmp_arr[ADS_READ_REG_COUNT] = {0,0,0};

struct CORE_1_MEM LMS_Fixed_Inst DFL_LMS_Inst;


  //////////////////////////////////////////////////////////////////////
 ///////////////////  CORE 0 FUNCTION DEFINITIONS   ///////////////////
//////////////////////////////////////////////////////////////////////
static void core_0_main();

static void USB_Handler(struct FFT_PARAMS *fft);

static void send_header_packet(uint16_t *h_data);
static void send_f_packets(Q15 *data, uint16_t num_samples);

static inline void fft_setup(struct FFT_PARAMS *cool_fft, uint16_t len, uint16_t maxtablesize);
static inline void fft_clear_fi(struct FFT_PARAMS *cool_fft);


  //////////////////////////////////////////////////////////////////////
 ///////////////////  CORE 1 FUNCTION DEFINITIONS   ///////////////////
//////////////////////////////////////////////////////////////////////
static void     core_1_main();
static void     transfer_results_to_safe_mem(Q15 *src, struct Transfer_Data *dst, uint16_t len);
static void     clear_adc_read_buffers();


  //////////////////////////////////////////////////////////////////////
 ////////////////////////////    Code!    /////////////////////////////
//////////////////////////////////////////////////////////////////////
// Main
// Start up in Core 0
int main(){
    board_init();
    tud_init(BOARD_TUD_RHPORT);

    init_LED_pins();

    Bandit_RGBU.R = 0;
    Bandit_RGBU.G = 0;
    Bandit_RGBU.B = 0;
    Bandit_RGBU.U = 0;
    set_RGB_levels(Bandit_RGBU.R, Bandit_RGBU.G, Bandit_RGBU.B);
    set_ULED_level(Bandit_RGBU.U);

    // Keep VDDA on, until sleep/low power modes are developed :)
    gpio_init(VDDA_EN_PAD);
    gpio_set_dir(VDDA_EN_PAD, GPIO_OUT);
    gpio_put(VDDA_EN_PAD, true);

    Setup_Semaphores();

    // Init h_hat core transfer register lengths to any known value.
    ICTXFR_A.len = 0;
    
    /*
        The AHB Lite cross bar is a 2:3 priority MUX that connects:
            - PIO0, PIO1, USB
        with the main AHB bus.

        USB falls in the lowest real time priority thus accesses to it
            (only Core 0) are regarded as lower priority.
        The access paths indicate wait-free access can be ensured for
            both white noise generation (DMA -> PIO0) and sampling
            (Core 1 <-> PIO1) if they have higher bus priority.
        
        Access allowance is done by gated high priority access, such that
            low priority access can occur. Sampling is not continuous,
            WGN generation is not continuous. But during their runtimes
            BOTH need 0 collisions.
    */

    // Allow Core 1 to have priority access to AHB Lite Bus
    //  This ensures the timing of sampling is deterministic
    hw_set_bits(&bus_ctrl_hw->priority, BUSCTRL_BUS_PRIORITY_PROC1_BITS);

    // Tenative allowance for High Priority DMA R/W access to AHB and APB
    //  buses for uninterrupted white noise generation.
    hw_set_bits(&bus_ctrl_hw->priority, BUSCTRL_BUS_PRIORITY_DMA_W_BITS);
    hw_set_bits(&bus_ctrl_hw->priority, BUSCTRL_BUS_PRIORITY_DMA_R_BITS);

    // Wait for bus priority changes to be applied.
    //  "In normal circumstances this occurs almost immediately"
    while(!bus_ctrl_hw->priority_ack);

    // Setup to count AHB-Lite MUX collisions
    bus_ctrl_hw->counter[0].value = 0;
    bus_ctrl_hw->counter[0].sel = arbiter_fastperi_perf_event_access_contested;


    // Initialize Status LEDs,
    //  Sequence Seen on Proper Init
    set_RGB_levels(BANDIT_PINK_SUPER_ARGUMENT);
    set_ULED_level(Bandit_RGBU.U = 10);

    // Setup for peripherals done on core 0
    multicore_launch_core1(core_1_main);
    core_0_main();
    // We should NEVER be here!!!
    while(1){
        // need something here to indicate we messed up.
        tight_loop_contents();
    }

}

  //////////////////////////////////////////////////////////////////////
 /////////////////    Core 0 Main Loop    /////////////////////////////
//////////////////////////////////////////////////////////////////////
static void core_0_main(){
    // Claim lock on settings until Core 0 can deal with initialization
    //  prevents Core 1 from starting any processing without settings
    //  in place.
    
    Acquire_Lock_Blocking(INTERCORE_SETTINGS_LOCK);
    
    // Do not start updated to prevent useless DSP cycling
    Global_Bandit_Settings.updated = false;
    Global_Bandit_Settings.settings_bf = BANDIT_DFL_SETTINGS;
    Global_Bandit_Settings.manual_tap_len_setting = 0;
    Global_Bandit_Settings.manual_error_limit = 0;
    Global_Bandit_Settings.manual_freq_range = 0;
    Global_Bandit_Settings.manual_lms_offset = 0;
    Global_Bandit_Settings.skip_lms = false;
    CLR_BANDIT_SETTING(Global_Bandit_Settings.settings_bf, BS_AUTO_RUN);
    SET_BANDIT_SETTING(Global_Bandit_Settings.settings_bf, BS_AUTO_SEND);

    Release_Lock(INTERCORE_SETTINGS_LOCK);

    // Setup Structs and Default Parameters for FFT
    struct FFT_PARAMS cool_fft;
    fft_setup(&cool_fft, DEFAULT_LMS_TAP_LEN, (uint16_t)SINTABLESIZE);

    // Initialize tinyUSB with board and start listening for start char from GUI
    tud_cdc_n_set_wanted_char(CDC_CTRL_CHAN, START_CHAR);
    USB_NEXT_STATE = USB_INIT;
    tud_cdc_n_set_wanted_char(CDC_CTRL_CHAN, START_CHAR);
    // USB State Machine, Settings Application, FFT

    uint32_t pace_timer = timer_hw->timerawl;
    //uint32_t pace_time_limit = 31250;
    uint32_t pace_time_limit = 100000;

    bool is_calibration_data = false;
    Q15 calibration_max = 0;

    while(1){
        tud_cdc_n_set_wanted_char(CDC_CTRL_CHAN, START_CHAR);
        tud_task();
        USB_STATE = USB_NEXT_STATE;

        //volatile uint32_t spinlock_irq_status_A;

        switch(USB_STATE) {
            case USB_INIT: {
                //need idle work until GUI is ready
                tud_task();
                USB_NEXT_STATE = USB_FFT_DATA_COLLECT;
            }
            break;
            
            case USB_APPLY_SETTINGS: {
                USB_NEXT_STATE = USB_FFT_DATA_COLLECT;
            }
            break;

            case USB_FFT_DATA_COLLECT: {
                // Acquire safe access to FFT mem, can use 2 locks for ping pong access
                tud_task();

                struct Transfer_Data *data_src;

                Acquire_Lock_Blocking(INTERCORE_FFTMEM_LOCK_A);
                pace_timer = timer_hw->timerawl;
                data_src = &ICTXFR_A;
                tud_task();
                
                if(!data_src->updated){
                    // FFT Data wasn't updated, shouldn't happen given semaphore
                    //  pacing structure
                    Release_Lock(INTERCORE_FFTMEM_LOCK_A);
                    USB_NEXT_STATE = USB_FFT_DATA_COLLECT;
                } else {
                    // If there is new FFT data to be had
                    data_src->updated = false;
                    // If data is all zeros (Core 1 probably gave up on convergence)
                    //  or the length is zero (P R O B L E M)
                    //  then don't run the FFT
                    bool allzeros = true;

                    is_calibration_data = data_src->calibration_data;

                    if(data_src->len && !SKIP_FFT){
                        // Apply windowing here if needed!!!
                        
                        fft_setup(&cool_fft, data_src->len, (uint16_t)SINTABLESIZE);

                        for(uint16_t n = 0; n < data_src->len; ++n){
                            if((cool_fft.fr[n] = data_src->data[n])) allzeros = false;
                            cool_fft.fi[n] = 0;
                        }
                    }

#ifdef FORCESEND_TESTING 
                    USB_NEXT_STATE = USB_RUN_DMC_JK_RUN_FFT;
#else
                    if(allzeros && !SKIP_FFT){
                        Release_Lock(INTERCORE_FFTMEM_LOCK_A);
                        USB_NEXT_STATE = USB_FFT_DATA_COLLECT;
                    } else {
                        USB_NEXT_STATE = USB_RUN_DMC_JK_RUN_FFT;
                    } 
#endif     
                }
            }
            break;
            
            case USB_RUN_DMC_JK_RUN_FFT: {
                tud_task();
                if(!SKIP_FFT){
                    FFT_fixdpt(&cool_fft);      // Run FFT
                    FFT_mag(&cool_fft);         // Extract magnitude, output in fft.fr
                    cool_fft.num_samples >>= 1; // Print only half of fft result, dodge reflected stuff
                    
                    if(is_calibration_data){
                        Q15 maxval = 0;
                        for(uint_fast16_t n = 0; n < cool_fft.num_samples; ++n){
                            if(cool_fft.fr[n] > maxval) maxval = cool_fft.fr[n];
                            //FFT_CAL_BUFF[n] = cool_fft.fr[n];
                            FFT_AVG_BUFF[n] = 0;
                        }

                        for(uint_fast16_t n = 0; n < cool_fft.num_samples; ++n){
                            FFT_CAL_BUFF[n] = maxval - cool_fft.fr[n];
                        }
                        
                        calibration_max = maxval;
                        
                    } else {
                        Q15 maxval = 0;
                        for(uint_fast16_t n = 0; n < cool_fft.num_samples; ++n) if(cool_fft.fr[n] > maxval) maxval = cool_fft.fr[n];

                        Q15 normalize_calibration = div_Q15(calibration_max, maxval);

                        for(uint_fast16_t n = 0; n < cool_fft.num_samples; ++n){
                            FFT_AVG_BUFF[n] += cool_fft.fr[n];
                            FFT_AVG_BUFF[n] >>= 1;
                            cool_fft.fr[n] = FFT_AVG_BUFF[n];
                           // cool_fft.fr[n] -= mul_Q15(FFT_CAL_BUFF[n], normalize_calibration);
                            //cool_fft.fr[n] <<= 3;    
                        }
                    }
                } else {
                    for(uint16_t n = 0; n < ICTXFR_A.len; ++n){
                        cool_fft.fr[n] = ICTXFR_A.data[n];
                        // Debug
                        //cool_fft.fr[n] = (Q15)n;
                    }    
                    cool_fft.num_samples = ICTXFR_A.len;
                }
                

#ifdef FORCESEND_NOFFT
                for(uint16_t n = 0; n < ICTXFR_A.len; ++n){
                        cool_fft.fr[n] = ICTXFR_A.data[n];
                }
#else
                
                
                // Raw Core 1 data bypass
                //if(CORE_0_SKIP_FFT){
                //    for(uint16_t n = 0; n < ICTXFR_A.len; ++n){
                //        cool_fft.fr[n] = ICTXFR_A.data[n];
                //    }
                //}
#endif

                // Free memory constraints
                //  stall for limiting packets per second
                if(!SKIP_FFT) while(timer_hw->timerawl - pace_timer < pace_time_limit) tud_task();
                // LMS Sends 2x as many bytes as usual FFT packets, so slow down A LOT
                else while(timer_hw->timerawl - pace_timer < (pace_time_limit << 1)) tud_task();
                Release_Lock(INTERCORE_FFTMEM_LOCK_A);
                tud_task();

                if(is_calibration_data) USB_NEXT_STATE = USB_FFT_DATA_COLLECT;
                else USB_NEXT_STATE = USB_SEND_TUSB;
            }
            break;

            case USB_SEND_TUSB: {
                // Transmit FFT Data to computer
                tud_task();
#ifdef FORCESEND_TESTING  
#ifndef FORCESEND_NOFFT
                // knock down giant DC peak...
                //for(uint16_t n = 0; n < cool_fft.log2_num_samples - 3; ++n){
                //    cool_fft.fr[n] = cool_fft.fr[cool_fft.log2_num_samples - 1];
                //}
                cool_fft.fr[0] = cool_fft.fr[1];
#endif                
                send_f_packets(cool_fft.fr, cool_fft.num_samples);
                tud_task();
                busy_wait_ms(100);
#else
                //if(!SKIP_FFT) cool_fft.fr[0] = cool_fft.fr[1];
                USB_Handler(&cool_fft);     //send data to GUI through tusb
#endif
                USB_NEXT_STATE = USB_FFT_DATA_COLLECT;
            }
            break;

            case USB_SEND_CORE_DEBUG: {
                // indicate to CORE 1 debug report is wanted
                Acquire_Lock_Blocking(INTERCORE_CORE_1_DBG_LOCK);

                // idk yet

                Release_Lock(INTERCORE_CORE_1_DBG_LOCK);
                USB_NEXT_STATE = USB_FFT_DATA_COLLECT;
            }
            break;
            
            default: {
                USB_NEXT_STATE = USB_FFT_DATA_COLLECT;
            }
            break; //need debug for USB_STATE error

        }

        
    }
}

  //////////////////////////////////////////////////////////////////////
 /////////////////    Core 1 Main Loop    /////////////////////////////
//////////////////////////////////////////////////////////////////////
static void core_1_main(){
    busy_wait_us_32(1000);
    Acquire_Lock_Blocking(INTERCORE_CORE_1_DBG_LOCK);
    Bandit_Debug_Report.epoch_core_1_boot_us = timer_hw->timelr;
    uint8_t Bandit_Calibration_State = BANDIT_UNCALIBRATED;
    Q15 Bandit_DC_Offset_Cal = 0;
    
    
    DFL_LMS_Inst.tap_len = DEFAULT_LMS_TAP_LEN;
    DFL_LMS_Inst.max_convergence_attempts = 4;

    // Setup LMS controller and buffering
    struct LMS_Fixed_Inst LMS_Inst;
    
    LMS_Struct_Init(&DFL_LMS_Inst, 
                        0x0666, 
                        0x2000, 
                        0, 
                        STD_MAX_SAMPLES, 
                        0
                        ); // Errors are just straight guesses rn, offset as well
    DFL_LMS_Inst.tap_len = DEFAULT_LMS_TAP_LEN;
    DFL_LMS_Inst.d_n = D_N_0;
    DFL_LMS_Inst.x_n = X_N_0;
    DFL_LMS_Inst.iteration_ct = STD_MAX_SAMPLES;
    DFL_LMS_Inst.d_n_offset = 0;
    DFL_LMS_Inst.learning_rate = 0x0020;    // 0.001
    DFL_LMS_Inst.averaging_counts_limit = 2;
    //DFL_LMS_Inst.learning_rate = 0x0003;    // 0.0001
    //DFL_LMS_Inst.learning_rate = 0x0008;    // 0.00025

    // Set default settings to local struct copy
    LMS_Struct_Equate(&DFL_LMS_Inst, &LMS_Inst);

    // Setup FIR component of the LMS
    struct Q15_FIR_PARAMS LMS_FIR;
    setup_Q15_FIR(&LMS_FIR, DEFAULT_LMS_TAP_LEN);
    LMS_FIR.size_true = TOTAL_ADAPTIVE_FIR_LEN;
    LMS_FIR.data = LMS_FIR_BANK;
    LMS_FIR.taps = LMS_H_HATS;
    
    LMS_Inst.max_convergence_attempts = 4;
    LMS_Inst.averaging_counts_limit = 2;
    LMS_Inst.averaging_counts = 0;

    /*
        For Tap Length Update:
            - Set LMS_Inst.tap_len = len
            - setup_Q15_FIR(&LMS_FIR, len)
            - len must be power of 2
    */

    Q15 DOWNSAMPLE_SAMP_BUFFR[DOWNSAMPLE_LEN];

    struct Q15_FIR_PARAMS CUT_125KHZ;
    setup_Q15_FIR(&CUT_125KHZ, DOWNSAMPLE_LEN);
    CUT_125KHZ.size_true = DOWNSAMPLE_LEN;
    CUT_125KHZ.taps = h125_taps;
    CUT_125KHZ.data = DOWNSAMPLE_SAMP_BUFFR;
   
    struct Q15_FIR_PARAMS CUT_62KHZ;
    setup_Q15_FIR(&CUT_62KHZ, DOWNSAMPLE_LEN);
    CUT_62KHZ.size_true = DOWNSAMPLE_LEN;
    CUT_62KHZ.taps = h62_taps;
    CUT_62KHZ.data = DOWNSAMPLE_SAMP_BUFFR;

    struct Q15_FIR_PARAMS CUT_31KHZ;
    setup_Q15_FIR(&CUT_31KHZ, DOWNSAMPLE_LEN);
    CUT_31KHZ.size_true = DOWNSAMPLE_LEN;
    CUT_31KHZ.taps = h31_taps;
    CUT_31KHZ.data = DOWNSAMPLE_SAMP_BUFFR;


    /*
        Initiate frontend PGA/MUX
            Set channel 0 (D_N), 1x gain
    */
    spi_inst_t *mcp_spi = spi1;
    MCP6S92_Init(mcp_spi, PGA_CSN_PAD, PGA_SCK_PAD, PGA_SI_PAD);
    // Don't init frontend PGA until calibration
    //MCP6S92_Send_Command_Raw(mcp_spi, MCP6S92_INSTR(MCP6S92_REG_WRITE, MCP6S92_CHANNEL_REGISTER), MCP6S92_CHAN_0, PGA_CSN_PAD);
    //MCP6S92_Send_Command_Raw(mcp_spi, MCP6S92_INSTR(MCP6S92_REG_WRITE, MCP6S92_GAIN_REGISTER), MCP6S92_x1_GAIN, PGA_CSN_PAD);
    

    /*
        Initialize ADC SPI w/ pio1
    */
    pio_ads7253_spi_init(pio1, 16, 1, 0, ADC_CSN_PAD, ADC_SDI_PAD, ADC_SDO_A_PAD, 0);

    Bandit_RGBU.B = 0;
    Bandit_RGBU.R = 0;
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

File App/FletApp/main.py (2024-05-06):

import matplotlib.axes
import matplotlib.axis
import matplotlib.figure
import matplotlib.lines
import webbrowser
from generic_include import *
from generic_include import BANDIT_SETTINGS_BYTES
from assets.ref import *
import serial
import webbrowser
# from enum import IntEnum
# import serial.tools.list_ports_osx as list_ports_osx
# import serial.tools.list_ports_windows as list_ports_windows
# import serial.tools.list_ports_linux as list_ports_linux
import serial.tools.list_ports as list_ports
import platform
import matplotlib
matplotlib.use('agg')
import matplotlib.pyplot as plt
import matplotlib.ticker as ticker
from itertools import chain
import struct 
import flet as ft
from flet.matplotlib_chart import MatplotlibChart
from flet import RouteChangeEvent
from multiprocess import Queue, Event
import multiprocessing
from multiprocessing import Queue, Lock
from threading import Thread
import time
from bitstring import BitArray
import numpy as np
os = platform.system()
negative_allowed_event = Event()
negative_allowed_event.clear()
start_event = Event()
queue_max = Event()
queue_max.clear()
settings_event = Event()

port_selections = []
# if os == MACOS_STR: 
#     for port in list_ports_osx.comports():
#         port_selections.append(ft.dropdown.Option(str(port).split(".")[1]))
# elif os == LINUX_STR:
#     for port in list_ports_linux.comports():
#         port_selections.append(ft.dropdown.Option(str(port)))
# # elif os == WINDOWS_STR:
# #     for port in list_ports_windows.comports():
# #         port_selections.append(ft.dropdown.Option(str(port)))
# else: pass

for port in list_ports.comports():
    print(port)
    port_selections.append(ft.dropdown.Option(str(port)))

taps_list =[]
size = len(parametric_taps)
for index in range(size):
    taps_list.append(ft.dropdown.Option(key=parametric_taps[index]))


range_list = []
size1 = len(frequency_ranges)
for index1 in range(size1):
    range_list.append(ft.dropdown.Option(key=index1, text=frequency_ranges[index1]))

data_port = Port()
ctrl_port = Port()

# init_graph = [0 for i in range(NUM_VALUES)]

Settings_Queue = Queue()
GraphEvent = Event()
##########################################################################################SERIALREAD
def serial_read(dataPort: Port, ctrlPort: Port, data_Queue: Queue, settings_Queue: Queue, page, lock):
    BYTES_PER_NUMBER = 2
    CDC_PACKET_LENGTH = 64

    def close_banner(e):
        page.banner.open = False
        page.update()
    
    x = 0
    while x < 1:
        is_conn = start_event.wait()
        try:
            if dataPort.name == ctrlPort.name:
                raise serial.SerialException
            DATACHANNEL = serial.Serial(
                port = dataPort.name,
                baudrate = 9600,
                bytesize = serial.EIGHTBITS,
                timeout = 1,

            )
            CTRLCHANNEL = serial.Serial(
                port= ctrlPort.name,
                baudrate=9600,
                bytesize = serial.EIGHTBITS,
                timeout = 1,
            )
            x = x + 1
            #send initial settings
            CTRLCHANNEL.write(b'~')
            print('start')
            CTRLCHANNEL.write(bytes(INIT_SETTINGS))
            # # # print(bytes(INIT_SETTINGS))
            # # #print(CTRLCHANNEL.read(64))
            setting = BitArray(hex=CTRLCHANNEL.read(SETTINGS_BF_LEN).hex())
            bandit_sett_bf = BitArray(hex=CTRLCHANNEL.read(4).hex())
            newfreqrange = BitArray(hex=CTRLCHANNEL.read(1).hex())
            newtaplen = BitArray(hex=CTRLCHANNEL.read(2).hex())
            new_err_limit = BitArray(hex=CTRLCHANNEL.read(2).hex())
            new_lms_offset = BitArray(hex=CTRLCHANNEL.read(2).hex())
            newlmsmax_attempts = BitArray(hex=CTRLCHANNEL.read(2).hex())
            newlearnin_rate = BitArray(hex=CTRLCHANNEL.read(2).hex())
            skip_lmsset = newlearnin_rate = BitArray(hex=CTRLCHANNEL.read(1).hex())
            skip_fftset = newlearnin_rate = BitArray(hex=CTRLCHANNEL.read(1).hex())
            print(setting)
            print(bandit_sett_bf)
            print(newfreqrange)
            print(newtaplen)
            print(new_err_limit)
            print(new_lms_offset)
            print(newlmsmax_attempts)
            print(newlearnin_rate)
            if(skip_fftset): 
                print("Skip FFT")
            if(skip_lmsset): 
                print("Skip LMS")
            # print(thing.bin)
            # CTRLCHANNEL.flush()
            while True:
                #if settings have been changed                
                if settings_event.is_set():
                    if settings_Queue.empty():
                        pass
                    else:
                        CTRLCHANNEL.write(b'~')
                        settings = settings_Queue.get(block=False)
                        print(settings)
                        CTRLCHANNEL.write(bytes(settings))
                        setting = BitArray(hex=CTRLCHANNEL.read(SETTINGS_BF_LEN).hex())
                        bandit_sett_bf = BitArray(hex=CTRLCHANNEL.read(4).hex())
                        newfreqrange = BitArray(hex=CTRLCHANNEL.read(1).hex())
                        newtaplen = BitArray(hex=CTRLCHANNEL.read(2).hex())
                        new_err_limit = BitArray(hex=CTRLCHANNEL.read(2).hex())
                        new_lms_offset = BitArray(hex=CTRLCHANNEL.read(2).hex())
                        newlmsmax_attempts = BitArray(hex=CTRLCHANNEL.read(2).hex())
                        newlearnin_rate = BitArray(hex=CTRLCHANNEL.read(2).hex())
                        skip_lmsset = newlearnin_rate = BitArray(hex=CTRLCHANNEL.read(1).hex())
                        skip_fftset = newlearnin_rate = BitArray(hex=CTRLCHANNEL.read(1).hex())
                        print(setting)
                        print(bandit_sett_bf)
                        print(newfreqrange)
                        print(newtaplen)
                        print(new_err_limit)
                        print(new_lms_offset)
                        print(newlmsmax_attempts)
                        print(newlearnin_rate)
                        if(skip_fftset): 
                            print("Skip FFT")
                        if(skip_lmsset): 
                            print("Skip LMS")
                        settings_event.clear()
                else:
                    if DATACHANNEL.in_waiting >= CDC_PACKET_LENGTH:
                        start = time.time()
                        header_data = DATACHANNEL.read(CDC_PACKET_LENGTH)
                        count = 0
                        CTRLCHANNEL.write(b'a')
                        num_samples = (header_data[3] * 256 + header_data[2]) * BYTES_PER_NUMBER
                        while DATACHANNEL.in_waiting < num_samples and count < 1000:
                            count = count + 1
                        f_data = DATACHANNEL.read(num_samples)
                        end = time.time()
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

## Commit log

2023-10-04 Big modification
    [BANDIT_Rev_0_0.kicad_pcb, BANDIT_Rev_0_0.kicad_sch]
2023-10-05 Cool adaptive filter simulation done :)
2023-10-05 Fixed out of range conditions
    [main.c]
2023-10-06 Fixed readme, made DSP Adaptive test more safe for failure conditions
    [main.c]
2023-10-08 Added frame stride to fix videos to ~1000 frames
    [main.c]
2023-10-09 Josh was here
    [BANDIT_Rev_0_0.kicad_sch]
2023-10-10 Added new riemann sum error output term
    [main.c]
2023-10-12 Added dev platform schematic, project kicad library, got AWGN down
    [Bandit_Dev_Platform.kicad_pcb, Bandit_Dev_Platform.kicad_sch]
2023-10-19 Added structure for prototype activity
2023-10-24 PIO DMA White noise generator sketch
    [main.c]
2023-10-25 PIO properly initiates pin, main core setting not needed anymore
2023-10-26 Swap to struct and dynamic structure for variable length
    [main.c]
2023-10-26 Allowed pico_sdk_import.cmake thru gitignore
    [ideal_tap_results.csv]
2023-11-11 Initial setup for Development Platform
    [Bandit_Dev_Platform.kicad_sch]
2023-11-11 Oopsie lock file include
    [NCP164_VDDA_Feedback.xlsx]
2023-11-16 Update dev sch
    [Bandit_Dev_Platform.kicad_sch]
2023-11-21 Filter added to PCB
    [Bandit_Dev_Platform.kicad_sch]
2023-11-21 Added Filter Round 2
    [Bandit_Dev_Platform.kicad_sch]
2023-11-21 protocol for device init
2023-11-21 started dev platform PCB
    [Bandit_Dev_Platform.kicad_pcb, Bandit_Dev_Platform.kicad_sch]
2023-11-21 update pcb, filter kinda done
    [Bandit_Dev_Platform.kicad_pcb, Bandit_Dev_Platform.kicad_sch]
2023-11-21 Josh said the tracks are great
    [Bandit_Dev_Platform.kicad_pcb, Bandit_Dev_Platform.kicad_sch]
2023-11-27 Fixing dev pcb
    [Bandit_Dev_Platform.kicad_pcb, Bandit_Dev_Platform.kicad_sch]
2023-11-27 Initial USB protocol draft
    [Bandit_Dev_Platform.kicad_pcb, Protocol.xlsx]
2023-11-28 PCB Fun
    [Bandit_Dev_Platform.kicad_pcb, Bandit_Dev_Platform.kicad_sch]
2023-11-30 PCB Update
    [Bandit_Dev_Platform.kicad_pcb, Bandit_Dev_Platform.kicad_sch]
2023-12-05 PCB Updates
    [Bandit_Dev_Platform.kicad_pcb]
2024-01-29 Started 0402 transition, PN conversions for fabrication
    [Bandit_Dev_Platform.kicad_sch]
2024-01-30 Pcb kinda worked on
    [Bandit_Dev_Platform.kicad_pcb, Bandit_Dev_Platform.kicad_sch, NCP164ASNASJ_Calculator.ods]
2024-01-31 Added circular buffer test, library otw
    [Bandit_Dev_Platform.kicad_pcb]
2024-01-31 Circular buffers added to RP2040 evaluation stack
    [Bandit_Dev_Platform.kicad_pcb]
2024-02-01 Fixed makefile for eval, linking is pretty good now
    [main.c]
2024-02-01 Builds with custom linker, cmake and include issues solved
    [main.c]
2024-02-01 I think custom linking works correctly, need to verify 100% but build and objdump look okay
    [main.c]
2024-02-05 Fixed filter to be cheap
    [Bandit_Dev_Platform.kicad_pcb, Bandit_Dev_Platform.kicad_sch]
2024-02-05 PCB stuff
    [Bandit_Dev_Platform.kicad_pcb]
2024-02-05 Fixed BNC issue, changed more parts to be free.99
    [Bandit_Dev_Platform.csv, Bandit_Dev_Platform.kicad_pcb, Bandit_Dev_Platform.kicad_sch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]
2024-02-05 Almost done w pcb
    [Bandit_Dev_Platform.kicad_pcb]
2024-02-06 More done
    [Bandit_Dev_Platform.kicad_pcb, Bandit_Dev_Platform.kicad_sch]
2024-02-06 Schematic cleanup
    [Bandit_Dev_Platform.kicad_sch]
2024-02-06 Started fab files, idiot checking pcb
    [Bandit_Dev_Platform-all-pos_JLC_pos_fmt.csv, Bandit_Dev_Platform_JLC_BOM_fmt.csv, _JLC_BOM_fmt.csv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]
2024-02-07 Added filter test board
    [Bandit_Dev_Platform-B_Cu.gbr, Bandit_Dev_Platform-B_Mask.gbr, Bandit_Dev_Platform-B_Paste.gbr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]
2024-02-10 Dev platform and Filter Test pcb polished, ordered
    [Bandit_Dev_Platform-B_Cu.gbr, Bandit_Dev_Platform-B_Mask.gbr, Bandit_Dev_Platform-B_Paste.gbr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]
2024-02-10 Need to update fab, but fixed C70 duplicate issue from version mismatch
    [Bandit_Dev_Platform.kicad_pcb, Bandit_Dev_Platform.kicad_sch]
2024-02-15 Really tired so ADS library is super unfinished, don't use or reference... yet
2024-02-24 Added Bandit_Pins header, RUN pin wasn't tied high.. hopefully wont be an issue lol
    [Bandit_Dev_Platform.kicad_sch]
2024-02-26 ADC Workin
2024-02-26 PGA Working, signal present to ADC. ADC Data not great
2024-02-27 initial multiprocessing TODO: fix graph updating and graph object communication between processes
    [generic_include.py, main.py]
2024-02-29 made graph faster w multiprocessing instead of threading
2024-03-05 fix data transfer delay + initial GUI improvements
    [main.py]
2024-03-07 when main thread ends, all other threads exit
2024-03-08 Issue narrowed down to pin overwrite with PIO, works fine in vacuum... Will fix tomorrow
    [main.c]
2024-03-08 Raw PIO SPI added
2024-03-15 MOSI not working, the rest is. REference PIO_ADS7253 for working MISO, will crack tmrw or something
    [main.c]
2024-03-21 Restructuring, updated Bandit_Template
    [ads7253_breakout-B_Cu.gbr, ads7253_breakout-B_Mask.gbr, ads7253_breakout-B_Paste.gbr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]
2024-03-30 Compiled Bandit_Template_USB, no functional verification, finifhing ADC library
2024-03-31 PIO ADC fully integrated with Bandit Template :)
2024-04-01 Uhhh calibration routine probably mostly there
2024-04-01 Better handling of DC calibration vs. runtime h(t) offset
2024-04-01 Added LMS sample counter, Fast AHB collision counter, cleaned up state logic
    [main.c]
2024-04-01 Fixed missing PGA settling time, parameterized PGA settling time
    [main.c]
2024-04-03 Added and tested ADS7253 REFDAC auto calibration routine
2024-04-04 Added default LMS Struct w/ settings, this cascades into allowing a default set state that will also change FFT settings OTF if a user resets to default state
    [main.c]
2024-04-04 Testing build million NOP sampling is super accurate, so it stays... lol
2024-04-04 Added FIR Filter
2024-04-05 added setting config and fixed isr
    [Bode_Bandit.h, main.c]
2024-04-08 Bandit is stuck on ADC setup again... shouldn't be
    [main.c]
2024-04-09 Okay, it works with fixed lengths and is awful. Stall on LMS params passed thru USB, not sure where the disconnect is
    [main.c]
2024-04-09 added WGN switch
2024-04-09 Error somewhere in core 0 state machine
    [main.c]
2024-04-10 fixed some GUI transfer and grpahing bugs
    [main.c, main.py]
2024-04-10 Printing sorta works, FFT results always 0
2024-04-12 fixed graph scaling 1
    [main.py]
2024-04-12 It's workingggggg (mostly)
    [Bandit_Dev_Platform.kicad_pcb]
2024-04-13 Found error in FFT :)
    [main.c]
2024-04-13 FFT Fixed, table shift indexing was being done slightly wrong :)
    [main.c]
2024-04-13 Fixed flags, reset LEDs to operational Core 1 tracking
    [main.c]
2024-04-15 Working FFT finally, dumb memory map issue
    [Bode_Bandit.h, main.c]
2024-04-17 fixed gui for windowsssssss
    [main.py]
2024-04-30 back to threading
2024-05-01 settings print back correctly now
    [generic_include.py, main.c, main.py]
2024-05-01 Not working w old code... hmmm
    [main.c]
2024-05-01 THIS IS THE BUILD FOR THE DAY DO NOT CHANGE PLS REVERT IF BROKE
    [main.c]
2024-05-06 Tenatively working, freq domain self calibration no worky
